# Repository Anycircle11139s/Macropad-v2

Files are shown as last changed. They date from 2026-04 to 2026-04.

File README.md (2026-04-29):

# Macropad-v2
<br>
<Br>

I wanted to make a second version of my macropad because I was confident, that with my improved skills, I could cook up something better. I spent a long time creating this, and I'm really proud of what I made. I just started by brainstorming what I wanted in my hackpad, and I searched up cool features to add, eventually ending with me designing a macropad and case with these items:
- Joystick
- 2 sliders
- 2 oleds
- buzzer
- Haptics
- rotary encoder
- cool cad case
- 12 switches
- Trackball
- hand gesture sensor
- bluetooth

Screenshot 2026-04-26 at 5 35 26 pm
<BR>
<br>

Screenshot 2026-04-26 at 5 40 05 pm
<BR>
<br>

Screenshot 2026-04-26 at 5 40 14 pm

<br>

<br>

BOM:
<Br>

|Name |Purpose |Quantity|Total Cost (USD)|Link |Distributor|
|---|---|---|---|---|---|
|Case |the case bruh |1 |6.50 | |Printing legion|
|PCB |the pcb ;( |1 |21.00 | |JLCPCB |
|lipo battery |battery |1 |0.99 |https://www.aliexpress.com/item/1005011541940994.html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 |ali express|
|joystick |for joy and happiness and sticks |2 |0.99 |https://www.aliexpress.com/item/1005006375332797.html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 |ali express|
|slide pot |sliders |2 |5.70 |https://www.aliexpress.com/item/1005008713345793.html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 |ali express|
|haptic motor |haptics |1 |1.82 |https://www.aliexpress.com/item/1005007159921749.html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 |ali express|
|trackball |trackball |1 |3.70 |https://www.aliexpress.com/item/1005008126890596.html?src=google#nav-description |ali express|
|tof sensor |hand gestures |1 |1.54 |https://www.aliexpress.com/item/1005006864257651.html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|ali express|
|DRV2605LDGS |haptics driver |1 |3.60 |https://www.aliexpress.com/item/1005009975089617.html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 |ali express|
|24LC256 |for extra memory |1 |3.67 |https://www.aliexpress.com/item/1005007758875314.html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 |Ali express|
|I2C channel switcher|so I can run I2C with that many things|1 |2.94 |https://www.aliexpress.com/item/4000321651168.html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 |ali express|
|ads1115 |for the sliders and joystick |1 |3.27 |https://www.aliexpress.com/item/4000116831589.html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 |ali express|
|io expander |more pins |1 |3.83 |https://www.aliexpress.com/item/1005006123427728.html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 |ali express|
|headers |headers |1 |1.23 |https://www.aliexpress.com/item/1005011980100152.html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 |ali express|
|buzzer |buzzing |2 |5.50 |https://www.aliexpress.com/item/1005007760117171.html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 |ali express|
|rotary encoder |to rotary encode |1 |1.29 |https://www.aliexpress.com/item/1005007644083514.html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 |ali express|
|150r resistors |resisting |1 |1.79 |https://www.aliexpress.com/item/1005011779163101.html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 |ali express|
|100r resistors |resisting |1 |1.79 |https://www.aliexpress.com/item/1005011779163101.html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 |ali express|
|2.2k resistors |resisting |1 |1.79 |https://www.aliexpress.com/item/1005011779163101.html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 |ali exress |
|m4 screws |to mount PCB |1 |1.31 |https://www.aliexpress.com/item/1005005879037174.html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! |ali express|
|m2 screws |to hold case together |1 |1.58 |https://www.aliexpress.com/item/1005005879037174.html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! |ali express|
|Keycaps |to cover switches |1 |4.20 |https://www.aliexpress.com/item/1005008678389468.html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! |ali express|
|Diodes |for switch matrix |1 |2.83 |https://www.aliexpress.com/item/1005007606166130.html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! |Ali express|
|Oleds |2 oleds |2 |7.00 |https://www.aliexpress.com/item/1005006636072295.html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! |ali express|
|Switches |buttons |1 |8.40 |https://www.aliexpress.com/item/1005006425450443.html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! |ali express|
|rgb leds |backlighting |1 |3.23 |https://www.aliexpress.com/item/1005005340818659.html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! |Ali express|
|Capacitors |to capacitate |1 |1.00 |https://www.aliexpress.com/item/1005010764953411.html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 |ali express|
|Xiao esp32 s3 |microcontroller |1 |11.00 |https://www.aliexpress.com/item/1005007870593864.html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 |ali express|
|Total | |113.50 | | ||

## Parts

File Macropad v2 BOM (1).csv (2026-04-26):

Name | Purpose | Quantity | Total Cost (USD) | Link | Distributor
Case | the case bruh | 1 | 6.50 |  | Printing legion
PCB | the pcb ;( | 1 | 21.00 |  | JLCPCB
lipo battery | battery | 1 | 0.99 | https://www.aliexpress.com/item/1005011541940994.html?curPageLogUid=xRO33uo723qw | ali express
joystick | for joy and happiness and sticks | 2 | 0.99 | https://www.aliexpress.com/item/1005006375332797.html?curPageLogUid=3UEUdfj2OnjF | ali express
slide pot | sliders | 2 | 5.70 | https://www.aliexpress.com/item/1005008713345793.html?curPageLogUid=FXsnTpFwKMfe | ali express
haptic motor | haptics | 1 | 1.82 | https://www.aliexpress.com/item/1005007159921749.html?curPageLogUid=zrmwNkYZNhYB | ali express
trackball | trackball | 1 | 3.70 | https://www.aliexpress.com/item/1005008126890596.html?src=google#nav-description | ali express
tof sensor | hand gestures | 1 | 1.54 | https://www.aliexpress.com/item/1005006864257651.html?curPageLogUid=MrmJQzMoGh3t | ali express
DRV2605LDGS | haptics driver | 1 | 3.60 | https://www.aliexpress.com/item/1005009975089617.html?curPageLogUid=5ZwdNp8fQ9ho | ali express
24LC256 | for extra memory | 1 | 3.67 | https://www.aliexpress.com/item/1005007758875314.html?curPageLogUid=d8mRjZi8dGUy | Ali express
I2C channel switcher | so I can run I2C with that many things | 1 | 2.94 | https://www.aliexpress.com/item/4000321651168.html?curPageLogUid=kvqc1Zd7ka2i | ali express
ads1115 | for the sliders and joystick | 1 | 3.27 | https://www.aliexpress.com/item/4000116831589.html?curPageLogUid=sNNybvIUvGwU | ali express
io expander | more pins | 1 | 3.83 | https://www.aliexpress.com/item/1005006123427728.html?curPageLogUid=0Dl325w86X0G | ali express
headers | headers | 1 | 1.23 | https://www.aliexpress.com/item/1005011980100152.html?curPageLogUid=sG8mgvOClCPu | ali express
buzzer | buzzing | 2 | 5.50 | https://www.aliexpress.com/item/1005007760117171.html?curPageLogUid=3fwWn3qz4T5N | ali express
rotary encoder | to rotary encode | 1 | 1.29 | https://www.aliexpress.com/item/1005007644083514.html?curPageLogUid=TOJyxlb254yR | ali express
150r resistors | resisting | 1 | 1.79 | https://www.aliexpress.com/item/1005011779163101.html?curPageLogUid=lPvCdQ65XX0q | ali express
100r resistors | resisting | 1 | 1.79 | https://www.aliexpress.com/item/1005011779163101.html?curPageLogUid=lPvCdQ65XX0q | ali express
2.2k resistors | resisting | 1 | 1.79 | https://www.aliexpress.com/item/1005011779163101.html?curPageLogUid=lPvCdQ65XX0q | ali exress
m4 screws | to mount PCB | 1 | 1.31 | https://www.aliexpress.com/item/1005005879037174.html?mp=1 | ali express
m2 screws | to hold case together | 1 | 1.58 | https://www.aliexpress.com/item/1005005879037174.html?mp=1 | ali express
Keycaps | to cover switches | 1 | 4.20 | https://www.aliexpress.com/item/1005008678389468.html?mp=1 | ali express
Diodes | for switch matrix | 1 | 2.83 | https://www.aliexpress.com/item/1005007606166130.html?mp=1 | Ali express
Oleds | 2 oleds | 2 | 7.00 | https://www.aliexpress.com/item/1005006636072295.html?mp=1 | ali express
Switches | buttons | 1 | 8.40 | https://www.aliexpress.com/item/1005006425450443.html?mp=1 | ali express
rgb leds | backlighting | 1 | 3.23 | https://www.aliexpress.com/item/1005005340818659.html?mp=1 | Ali express
Capacitors | to capacitate | 1 | 1.00 | https://www.aliexpress.com/item/1005010764953411.html?curPageLogUid=IRwD1Amro2MH | ali express
Xiao esp32 s3 | microcontroller | 1 | 11.00 | https://www.aliexpress.com/item/1005007870593864.html?curPageLogUid=QZZSsXEuP658 | ali express

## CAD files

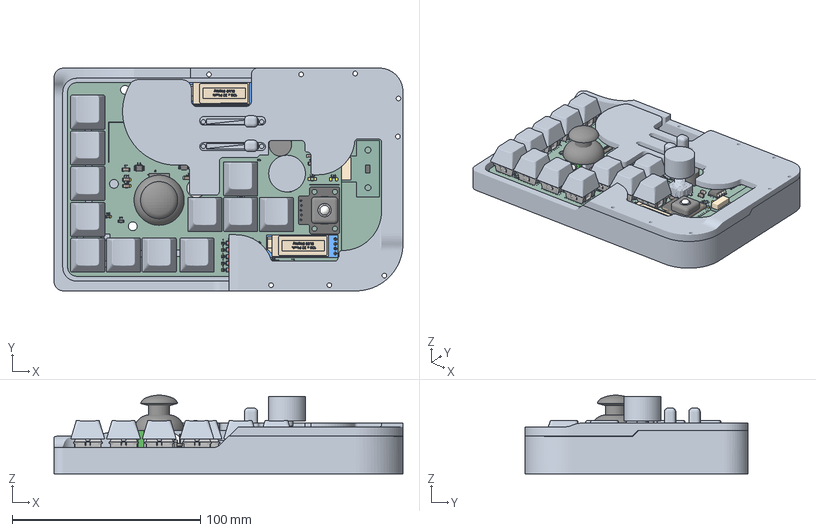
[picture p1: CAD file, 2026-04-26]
Macropad v2 CAD files/Final assembly of macropad v2.3mf
185.5 x 118.4 x 41.8 mm
Lever x 2
MeshBody1

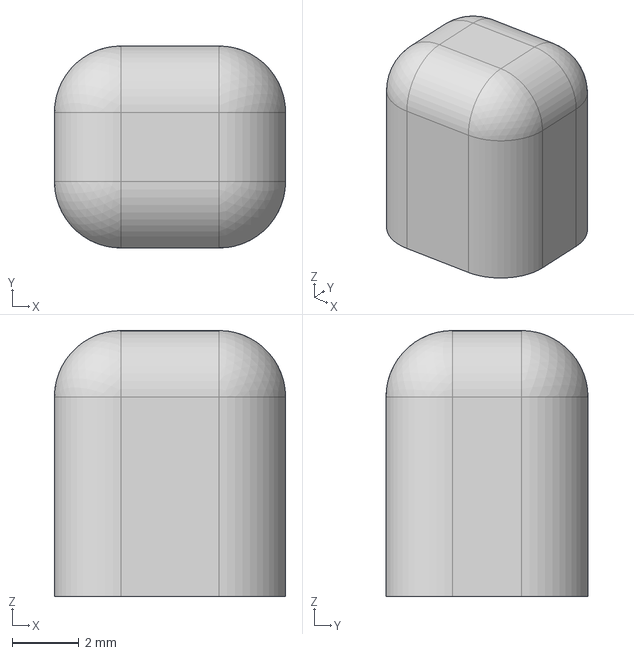
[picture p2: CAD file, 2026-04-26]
Macropad v2 CAD files/Body 5 of macropad v2.step
6.95 x 6.08 x 8.00 mm

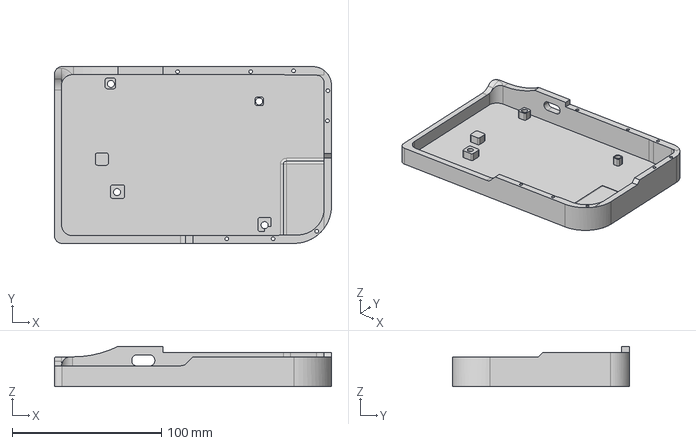
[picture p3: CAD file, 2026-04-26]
Macropad v2 CAD files/Body 1 of macropad v2.step
185.5 x 118.4 x 27.0 mm

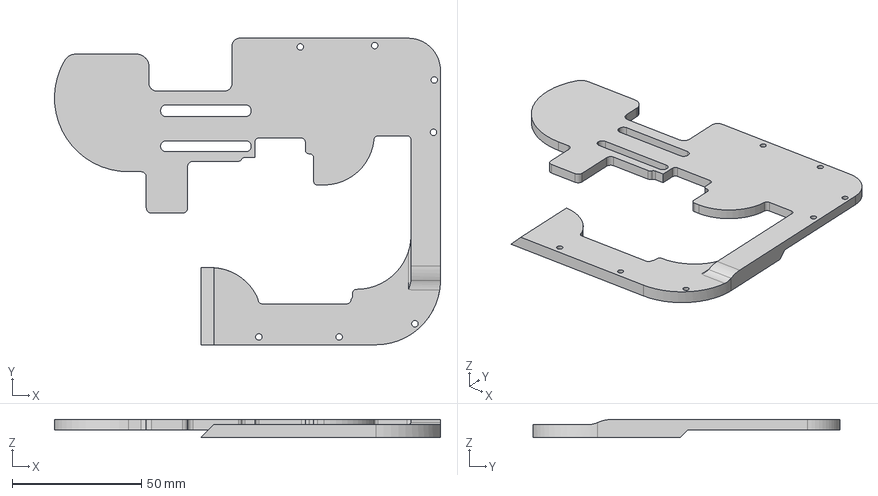
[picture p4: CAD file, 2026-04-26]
Macropad v2 CAD files/Body 2 of macropad v2.step
149.0 x 118.4 x 7.00 mm

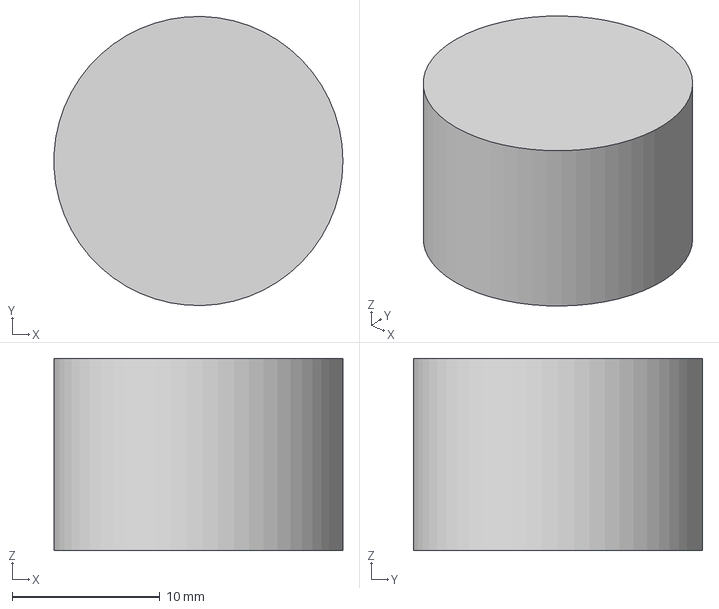
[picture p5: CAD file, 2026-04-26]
Macropad v2 CAD files/Body 3 of macropad v2.step
19.5 x 19.5 x 13.0 mm

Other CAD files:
Macropad v2 CAD files/Body 4 of macropad v2.step
Macropad v2 CAD files/Body 1 of macropad v2.3mf
Macropad v2 CAD files/Body 2 of macropad v2.3mf
Macropad v2 CAD files/Body 3 of macropad v2.3mf
Macropad v2 CAD files/Body 4 of macropad v2.3mf
Macropad v2 CAD files/Body 5 of macropad v2.3mf

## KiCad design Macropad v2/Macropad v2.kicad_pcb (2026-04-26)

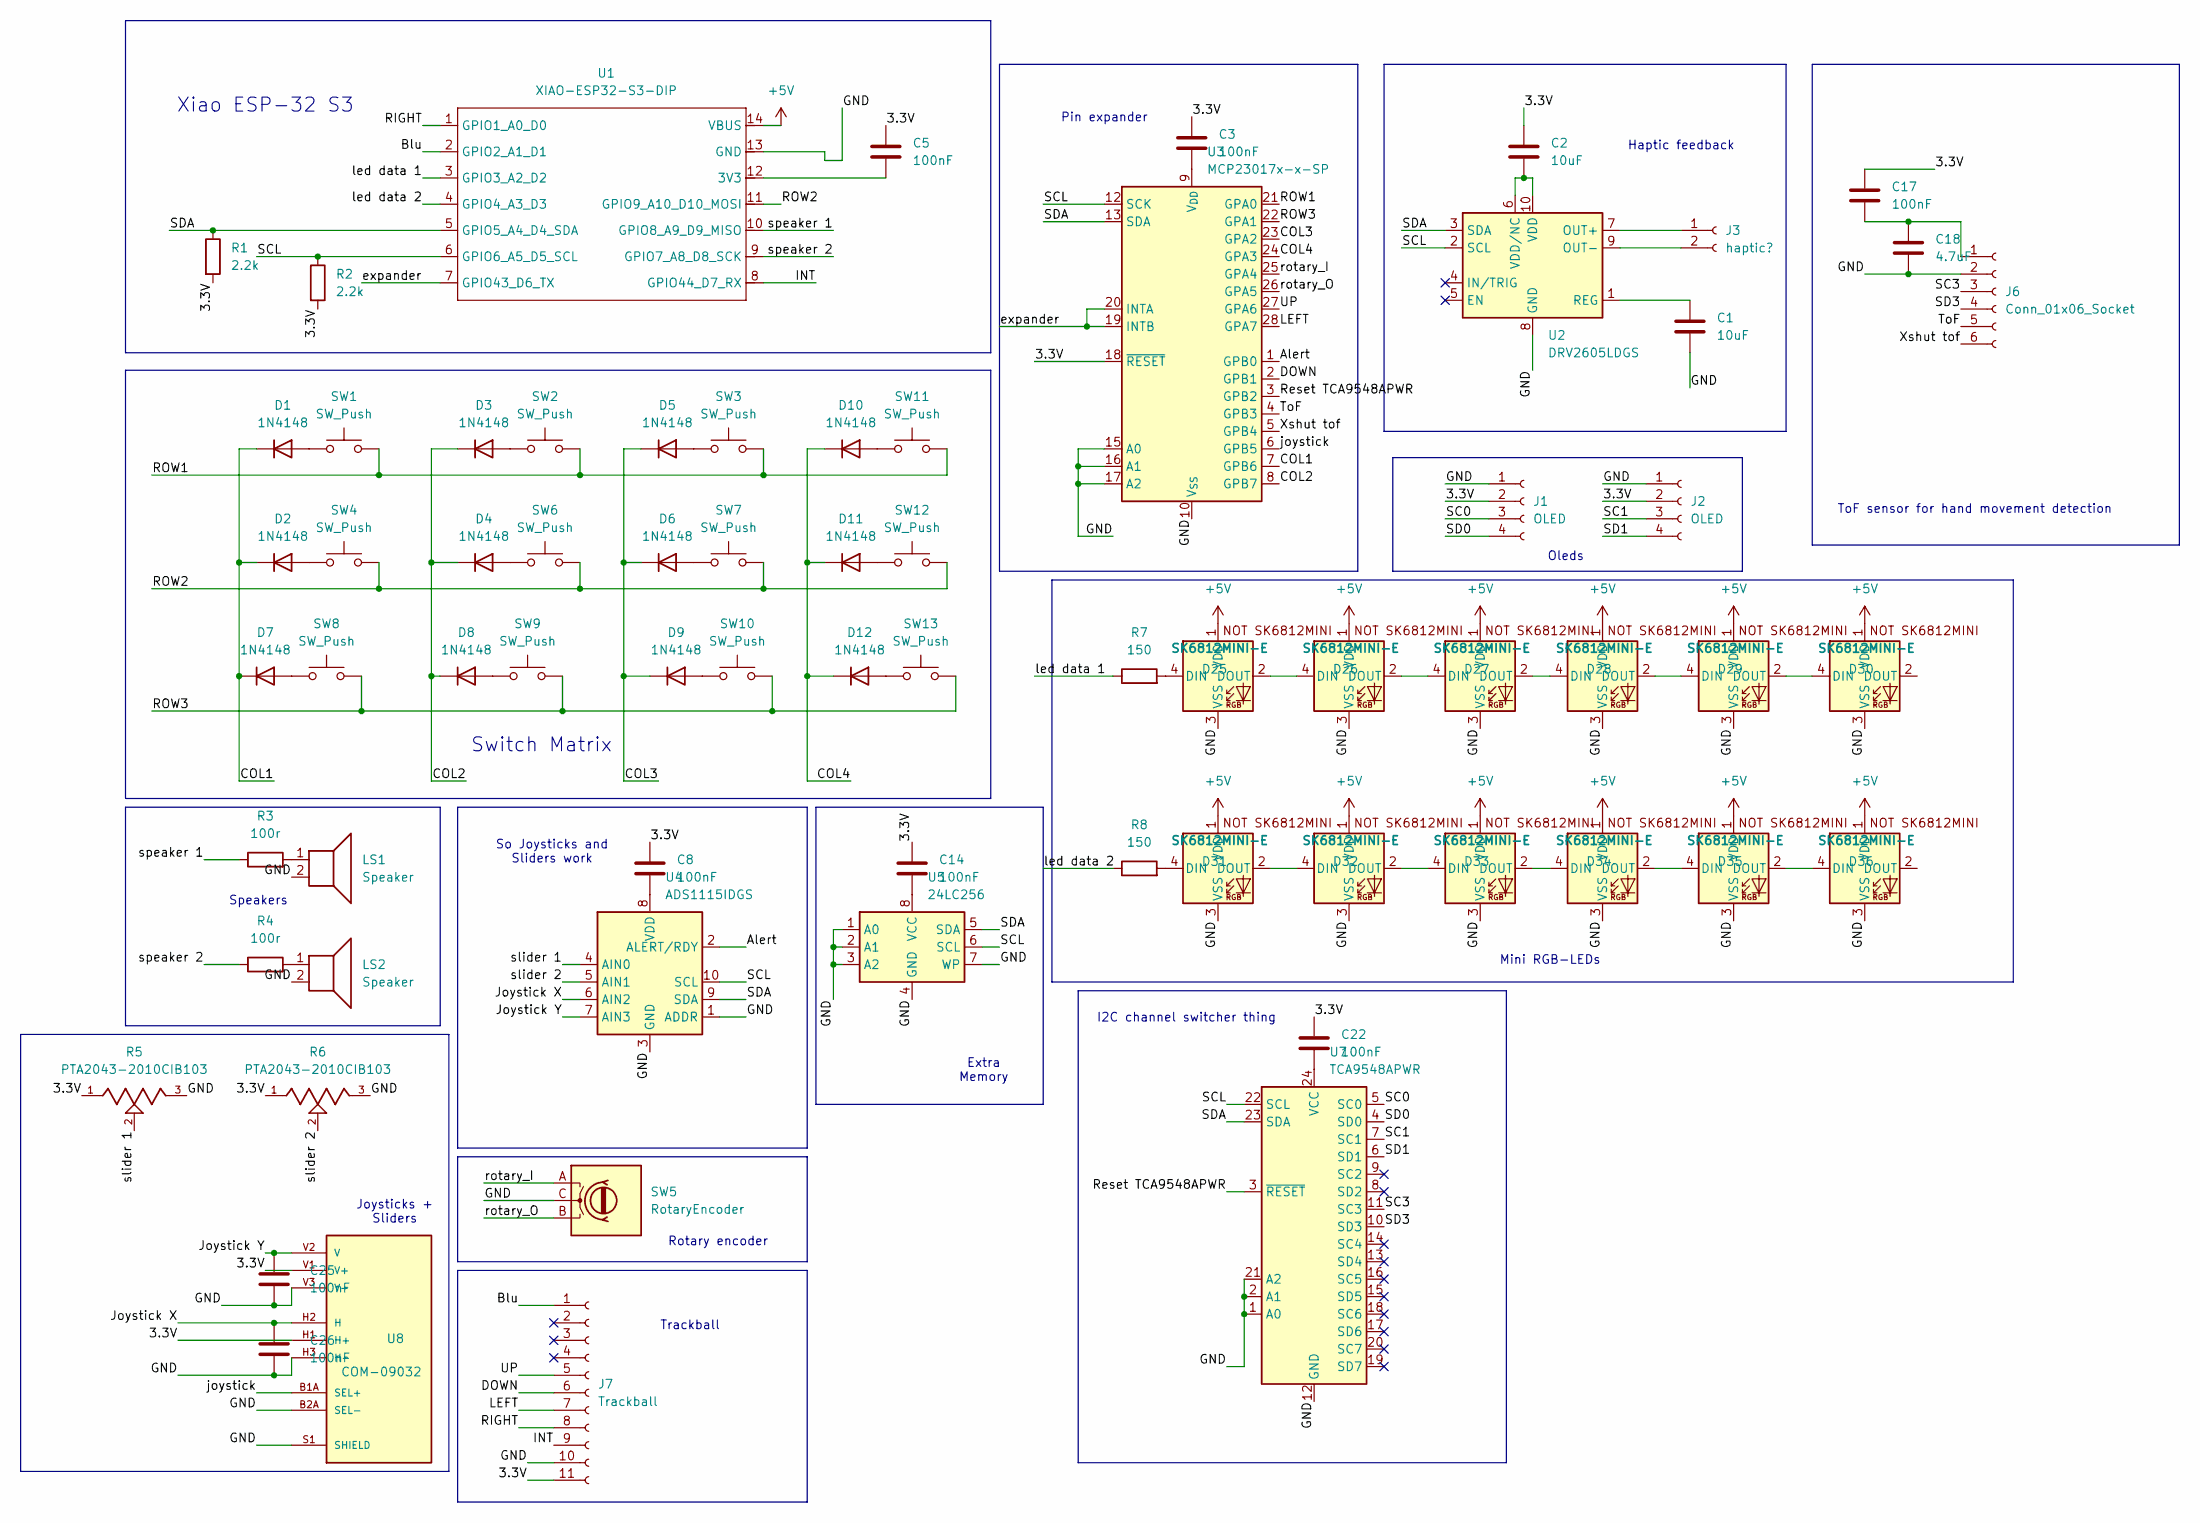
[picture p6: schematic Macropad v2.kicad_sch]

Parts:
C1, C2: 10uF; C_1206_3216Metric_Pad1.33x1.80mm_HandSolder
C3, C5, C8, C14, C17, C22, C25, C26: 100nF; C_1206_3216Metric_Pad1.33x1.80mm_HandSolder
C18: 4.7uF; C_1206_3216Metric_Pad1.33x1.80mm_HandSolder
D1, D2, D3, D4, D5, D6, D7, D8, D9, D10, D11, D12: 1N4148; D_DO-35_SOD27_P7.62mm_Horizontal
D25, D26, D27, D28, D29, D30, D31, D32, D33, D34, D35, D36: SK6812MINI-E; SK6812MINI-E Fixed
J1, J2: OLED; SSD1306-0.91-OLED-4pin-128x32
J3: haptic?; PinHeader_1x02_P2.54mm_Vertical
J6: Conn_01x06_Socket; PinHeader_1x06_P2.54mm_Vertical
J7: Trackball; PinHeader_1x11_P2.54mm_Vertical
LS1, LS2: Speaker; XDCR_CMI-1210-5-95T
R1, R2: 2.2k; R_0805_2012Metric_Pad1.20x1.40mm_HandSolder
R3, R4: 100r; R_0805_2012Metric_Pad1.20x1.40mm_HandSolder
R5, R6: PTA2043-2010CIB103; TRIM_PTA2043-2010CIB103; PARTREV 04/21
R7, R8: 150; R_0805_2012Metric_Pad1.20x1.40mm_HandSolder
SW1, SW2, SW3, SW4, SW6, SW7, SW8, SW9, SW10, SW11, SW12, SW13: SW_Push; SW_Cherry_MX_1.00u_PCB
SW5: RotaryEncoder; RotaryEncoder_Alps_EC11E-Switch_Vertical_H20mm
U1: XIAO-ESP32-S3-DIP
U2: DRV2605LDGS; TSSOP-10_3x3mm_P0.5mm
U3: MCP23017x-x-SP; DIP-28_W7.62mm
U4: ADS1115IDGS; TSSOP-10_3x3mm_P0.5mm
U5: 24LC256; DIP-8_W7.62mm
U7: TCA9548APWR; TSSOP-24_4.4x7.8mm_P0.65mm
U8: COM-09032; XDCR_COM-09032; PARTREV N/A

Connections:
+5V: D25.1 (VDD), D26.1 (VDD), D27.1 (VDD), D28.1 (VDD), D29.1 (VDD), D30.1 (VDD), D31.1 (VDD), D32.1 (VDD), D33.1 (VDD), D34.1 (VDD), D35.1 (VDD), D36.1 (VDD), U1.14 (VBUS)
/3.3V: C2.1, C3.1, C5.1, C8.1, C14.1, C17.1, C22.1, J1.2, J2.2, J7.11, R1.2, R2.2, R5.1, R6.1, U3.18 (~RESET), U8.H1 (H+), U8.V1 (V+)
/Alert: U3.1 (GPB0), U4.2 (ALERT/RDY)
/Blu: J7.1, U1.2 (GPIO2_A1_D1)
/COL1: D1.1 (K), D2.1 (K), D7.1 (K), U3.7 (GPB6)
/COL2: D3.1 (K), D4.1 (K), D8.1 (K), U3.8 (GPB7)
/COL3: D5.1 (K), D6.1 (K), D9.1 (K), U3.23 (GPA2)
/COL4: D10.1 (K), D11.1 (K), D12.1 (K), U3.24 (GPA3)
/DOWN: J7.6, U3.2 (GPB1)
/GND: C1.2, C18.2, C25.2, C26.2, D25.3 (VSS), D26.3 (VSS), D27.3 (VSS), D28.3 (VSS), D29.3 (VSS), D30.3 (VSS), D31.3 (VSS), D32.3 (VSS), D33.3 (VSS), D34.3 (VSS), D35.3 (VSS), D36.3 (VSS), J1.1, J2.1, J6.2, J7.10, LS1.2, LS2.2, R5.3, R6.3, SW5.C, U1.13 (GND), U2.8 (GND), U3.10 (V_{SS}), U3.15 (A0), U3.16 (A1), U3.17 (A2), U4.1 (ADDR), U4.3 (GND), U5.1 (A0), U5.2 (A1), U5.3 (A2), U5.4 (GND), U5.7 (WP), U7.1 (A0), U7.2 (A1), U7.12 (GND), U7.21 (A2), U8.B2A (SEL-), U8.H3 (H-), U8.S1 (SHIELD), U8.S2 (SHIELD), U8.S3 (SHIELD), U8.S4 (SHIELD), U8.V3 (V-)
/INT: J7.9, U1.8 (GPIO44_D7_RX)
/Joystick X: C26.1, U4.6 (AIN2), U8.H2 (H)
/Joystick Y: C25.1, U4.7 (AIN3), U8.V2 (V)
/LEFT: J7.7, U3.28 (GPA7)
/RIGHT: J7.8, U1.1 (GPIO1_A0_D0)
/ROW1: SW1.2, SW2.2, SW3.2, SW11.2, U3.21 (GPA0)
/ROW2: SW4.2, SW6.2, SW7.2, SW12.2, U1.11 (GPIO9_A10_D10_MOSI)
/ROW3: SW8.2, SW9.2, SW10.2, SW13.2, U3.22 (GPA1)
/Reset TCA9548APWR: U3.3 (GPB2), U7.3 (~RESET)
/SC0: J1.3, U7.5 (SC0)
/SC1: J2.3, U7.7 (SC1)
/SC3: J6.3, U7.11 (SC3)
/SCL: R2.1, U1.6 (GPIO6_A5_D5_SCL), U2.2 (SCL), U3.12 (SCK), U4.10 (SCL), U5.6 (SCL), U7.22 (SCL)
/SD0: J1.4, U7.4 (SD0)
/SD1: J2.4, U7.6 (SD1)
/SD3: J6.4, U7.10 (SD3)
/SDA: R1.1, U1.5 (GPIO5_A4_D4_SDA), U2.3 (SDA), U3.13 (SDA), U4.9 (SDA), U5.5 (SDA), U7.23 (SDA)
/ToF: J6.5, U3.4 (GPB3)
/UP: J7.5, U3.27 (GPA6)
/Xshut tof: J6.6, U3.5 (GPB4)
/expander: U1.7 (GPIO43_D6_TX), U3.19 (INTB), U3.20 (INTA)
/joystick: U3.6 (GPB5), U8.B1A (SEL+)
/led data 1: R7.1, U1.3 (GPIO3_A2_D2)
/led data 2: R8.1, U1.4 (GPIO4_A3_D3)
/rotary_I: SW5.A, U3.25 (GPA4)
/rotary_O: SW5.B, U3.26 (GPA5)
/slider 1: R5.2, U4.4 (AIN0)
/slider 2: R6.2, U4.5 (AIN1)
/speaker 1: R3.1, U1.10 (GPIO8_A9_D9_MISO)
/speaker 2: R4.1, U1.9 (GPIO7_A8_D8_SCK)
unnamed: D1.2 (A), SW1.1
unnamed: D2.2 (A), SW4.1
unnamed: D3.2 (A), SW2.1
unnamed: D4.2 (A), SW6.1
unnamed: D5.2 (A), SW3.1
unnamed: D6.2 (A), SW7.1
unnamed: D7.2 (A), SW8.1
unnamed: D8.2 (A), SW9.1
unnamed: D9.2 (A), SW10.1
unnamed: D10.2 (A), SW11.1
unnamed: D11.2 (A), SW12.1
unnamed: D12.2 (A), SW13.1
unnamed: D25.4 (DIN), R7.2
unnamed: D25.2 (DOUT), D26.4 (DIN)
unnamed: D26.2 (DOUT), D27.4 (DIN)
unnamed: D27.2 (DOUT), D28.4 (DIN)
unnamed: D28.2 (DOUT), D29.4 (DIN)
unnamed: D29.2 (DOUT), D30.4 (DIN)
unnamed: D31.4 (DIN), R8.2
unnamed: D31.2 (DOUT), D32.4 (DIN)
unnamed: D32.2 (DOUT), D33.4 (DIN)
unnamed: D33.2 (DOUT), D34.4 (DIN)
unnamed: D34.2 (DOUT), D35.4 (DIN)
unnamed: D35.2 (DOUT), D36.4 (DIN)
unnamed: J3.1, U2.7 (OUT+)
unnamed: J3.2, U2.9 (OUT-)
unnamed: C17.2, C18.1, J6.1
unnamed: LS1.1, R3.2
unnamed: LS2.1, R4.2
unnamed: C5.2, U1.12 (3V3)
unnamed: C1.1, U2.1 (REG)
unnamed: C2.2, U2.6 (VDD/NC), U2.10 (VDD)
unnamed: C3.2, U3.9 (V_{DD})
unnamed: C8.2, U4.8 (VDD)
unnamed: C14.2, U5.8 (VCC)
unnamed: C22.2, U7.24 (VCC)

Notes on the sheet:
Trackball
Rotary encoder
Switch Matrix
Xiao ESP-32 S3
So Joysticks and Sliders work
Mini RGB-LEDs
I2C channel switcher thing
Oleds
Extra Memory
ToF sensor for hand movement detection
Pin expander
Speakers
Joysticks + Sliders
Haptic feedback

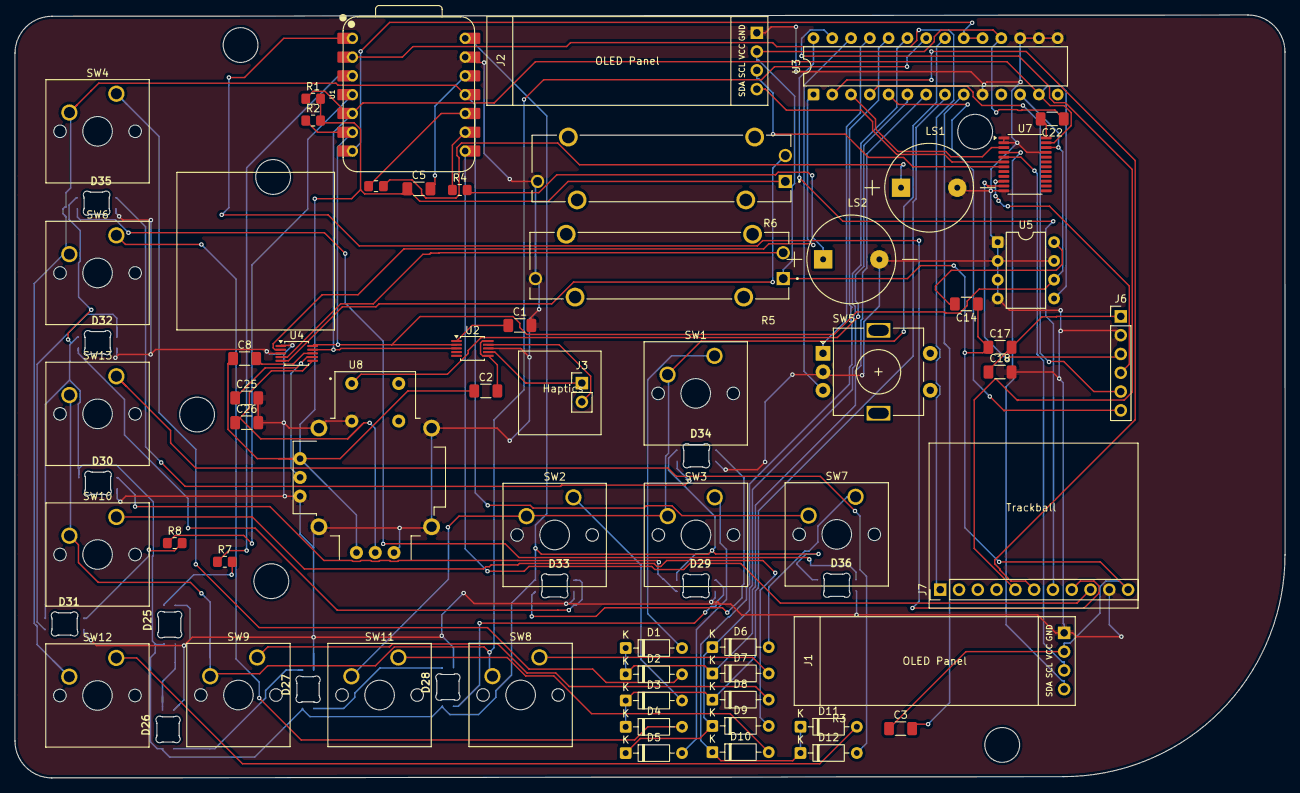
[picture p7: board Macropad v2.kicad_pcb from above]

Board: 2 copper layers, 171.7 x 103.2 mm, 70 parts (0 on the bottom side), 76 nets.

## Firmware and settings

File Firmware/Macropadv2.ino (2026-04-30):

#include <Wire.h>
#include <Adafruit_MCP23X17.h>
#include <Adafruit_ADS1X15.h>
#include <Adafruit_GFX.h>
#include <Adafruit_SSD1306.h>
#include <Adafruit_DRV2605.h>
#include <FastLED.h>
#include "USB.h"
#include "USBHIDKeyboard.h"
#include "USBHIDMouse.h"

// ==========================================
// 1. HARDWARE CONFIGURATION (VERIFY THESE!)
// ==========================================

// --- I2C Multiplexer (TCA9548A) ---
#define TCAADDR 0x70
#define OLED_1_CH 0 // Channel for Left OLED
#define OLED_2_CH 1 // Channel for Right OLED

// --- Switch Matrix (via MCP23017) ---
const int NUM_ROWS = 3;
const int NUM_COLS = 4;
// MAP THESE TO YOUR MCP23017 PINS (0-7 = GPA, 8-15 = GPB)
const uint8_t rowPins[NUM_ROWS] = {0, 1, 2};    // Example: GPA0, GPA1, GPA2
const uint8_t colPins[NUM_COLS] = {8, 9, 10, 11}; // Example: GPB0, GPB1, GPB2, GPB3

// Keymap matching your 3x4 grid
const char keyMap[NUM_ROWS][NUM_COLS] = {
  {'1', '2', '3', '4'},
  {'Q', 'W', 'E', 'R'},
  {'A', 'S', 'D', 'F'}
};
bool keyStates[NUM_ROWS][NUM_COLS] = {false};

// --- Trackball (Assuming GPIO direct to ESP32) ---
// If your trackball is I2C, this logic changes. Assuming 4 hall sensors here.
#define TB_UP    D1 
#define TB_DOWN  D2
#define TB_LEFT  D3
#define TB_RIGHT D4
#define TB_SPEED 2

// --- RGB LEDs (SK6812) ---
#define LED_PIN     D0 // "led data 1" pin
#define NUM_LEDS    10 // Adjust to your actual LED count
CRGB leds[NUM_LEDS];

// ==========================================
// 2. GLOBAL OBJECTS
// ==========================================

USBHIDKeyboard Keyboard;
USBHIDMouse Mouse;

Adafruit_SSD1306 display1(128, 32, &Wire, -1);
Adafruit_SSD1306 display2(128, 32, &Wire, -1);
Adafruit_ADS1115 ads;
Adafruit_MCP23X17 mcp;
Adafruit_DRV2605 drv;

unsigned long lastOLEDUpdate = 0;

// ==========================================
// 3. HELPER FUNCTIONS
// ==========================================

// Switch I2C Multiplexer Channel
void tcaselect(uint8_t i) {
  if (i > 7) return;
  Wire.beginTransmission(TCAADDR);
  Wire.write(1 << i);
  Wire.endTransmission();
}

// Trigger Haptic Feedback
void playHapticClick() {
  drv.setWaveform(0, 1);  // 1 = Strong Click (from DRV2605 library)
  drv.setWaveform(1, 0);  // End sequence
  drv.go();
}

// ==========================================
// 4. SETUP
// ==========================================

void setup() {
  Serial.begin(115200);
  
  // Start USB HID
  USB.begin();
  Keyboard.begin();
  Mouse.begin();

  // Start I2C
  Wire.begin();
  Wire.setClock(400000); // 400kHz for snappy matrix scanning

  // Init LEDs
  FastLED.addLeds<SK6812, LED_PIN, GRB>(leds, NUM_LEDS);
  FastLED.setBrightness(60);
  fill_solid(leds, NUM_LEDS, CRGB::Cyan);
  FastLED.show();

  // Init MCP23017 Matrix
  if (!mcp.begin_I2C()) {
    Serial.println("MCP23017 missing.");
  } else {
    // Set columns as INPUT_PULLUP
    for (int c = 0; c < NUM_COLS; c++) {
      mcp.pinMode(colPins[c], INPUT_PULLUP);
    }
    // Set rows as OUTPUT and HIGH
    for (int r = 0; r < NUM_ROWS; r++) {
      mcp.pinMode(rowPins[r], OUTPUT);
      mcp.digitalWrite(rowPins[r], HIGH);
    }
  }

  // Init ADS1115
  ads.setGain(GAIN_ONE); // +/- 4.096V
  if (!ads.begin()) { Serial.println("ADS1115 missing."); }

  // Init Haptics
  if (!drv.begin()) {
    Serial.println("DRV2605 missing.");
  } else {
    drv.selectLibrary(1);
    drv.setMode(DRV2605_MODE_INTTRIG);
  }

  // Init OLED 1
  tcaselect(OLED_1_CH);
  if(display1.begin(SSD1306_SWITCHCAPVCC, 0x3C)) {
    display1.clearDisplay();
    display1.setTextColor(SSD1306_WHITE);
    display1.setCursor(10, 10);
    display1.print("SYSTEM READY");
    display1.display();
  }

  // Init Trackball Pins
  pinMode(TB_UP, INPUT_PULLUP);
  pinMode(TB_DOWN, INPUT_PULLUP);
  pinMode(TB_LEFT, INPUT_PULLUP);
  pinMode(TB_RIGHT, INPUT_PULLUP);
}

// ==========================================
// 5. MAIN LOOP
// ==========================================

void loop() {
  
  // --- A. SCAN SWITCH MATRIX ---
  for (int r = 0; r < NUM_ROWS; r++) {
    // Pull the current row LOW
    mcp.digitalWrite(rowPins[r], LOW);
    
    for (int c = 0; c < NUM_COLS; c++) {
      // Read the column. LOW means pressed (because of pullups)
      bool isPressed = !mcp.digitalRead(colPins[c]);
      
      // State change detection
      if (isPressed && !keyStates[r][c]) {
        keyStates[r][c] = true;
        Keyboard.press(keyMap[r][c]);
        playHapticClick();
        
        // Visual feedback
        leds[0] = CRGB::White; 
        FastLED.show();
      } 
      else if (!isPressed && keyStates[r][c]) {
        keyStates[r][c] = false;
        Keyboard.release(keyMap[r][c]);
        
        leds[0] = CRGB::Cyan; 
        FastLED.show();
      }
    }
    // Return row to HIGH before moving to next
    mcp.digitalWrite(rowPins[r], HIGH);
  }


  // --- B. READ ANALOG JOYSTICK ---
  // ADC range for GAIN_ONE is roughly 0 to 26600 for 3.3V
  int16_t joyX = ads.readADC_SingleEnded(0); 
  int16_t joyY = ads.readADC_SingleEnded(1); 
  
  // Define Center deadzone (Assumes center is ~13300)
  int deadzone = 2000;
  int center = 13300;
  int mouseX = 0;
  int mouseY = 0;

  if (joyX > (center + deadzone)) mouseX = map(joyX, center + deadzone, 26600, 1, 10);
  if (joyX < (center - deadzone)) mouseX = map(joyX, center - deadzone, 0, -1, -10);
  
  if (joyY > (center + deadzone)) mouseY = map(joyY, center + deadzone, 26600, 1, 10);
  if (joyY < (center - deadzone)) mouseY = map(joyY, center - deadzone, 0, -1, -10);

  if (mouseX != 0 || mouseY != 0) {
    Mouse.move(mouseX, mouseY);
  }


  // --- C. READ TRACKBALL ---
  if (!digitalRead(TB_UP))    Mouse.move(0, -TB_SPEED);
  if (!digitalRead(TB_DOWN))  Mouse.move(0, TB_SPEED);
  if (!digitalRead(TB_LEFT))  Mouse.move(-TB_SPEED, 0);
  if (!digitalRead(TB_RIGHT)) Mouse.move(TB_SPEED, 0);


  // --- D. UPDATE OLEDS (Non-Blocking) ---
  // Only update screens every 100ms to prevent lagging the matrix scanner
  if (millis() - lastOLEDUpdate > 100) {
    tcaselect(OLED_1_CH);
    display1.clearDisplay();
    display1.setCursor(0,0);
    display1.print("X: "); display1.println(joyX);
    display1.print("Y: "); display1.println(joyY);
    display1.display();

    lastOLEDUpdate = millis();
  }

  // Breathing room for I2C bus stability
  delay(5); 
}
